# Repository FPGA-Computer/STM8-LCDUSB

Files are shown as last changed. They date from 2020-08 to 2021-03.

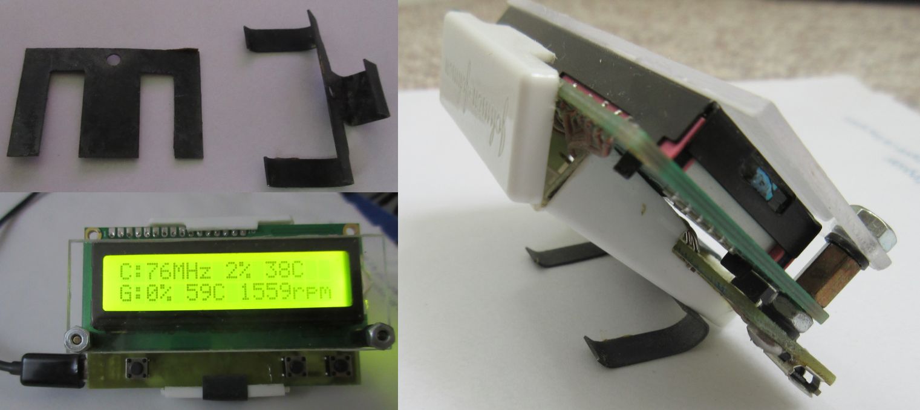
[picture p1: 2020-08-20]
LCD stand.jpg

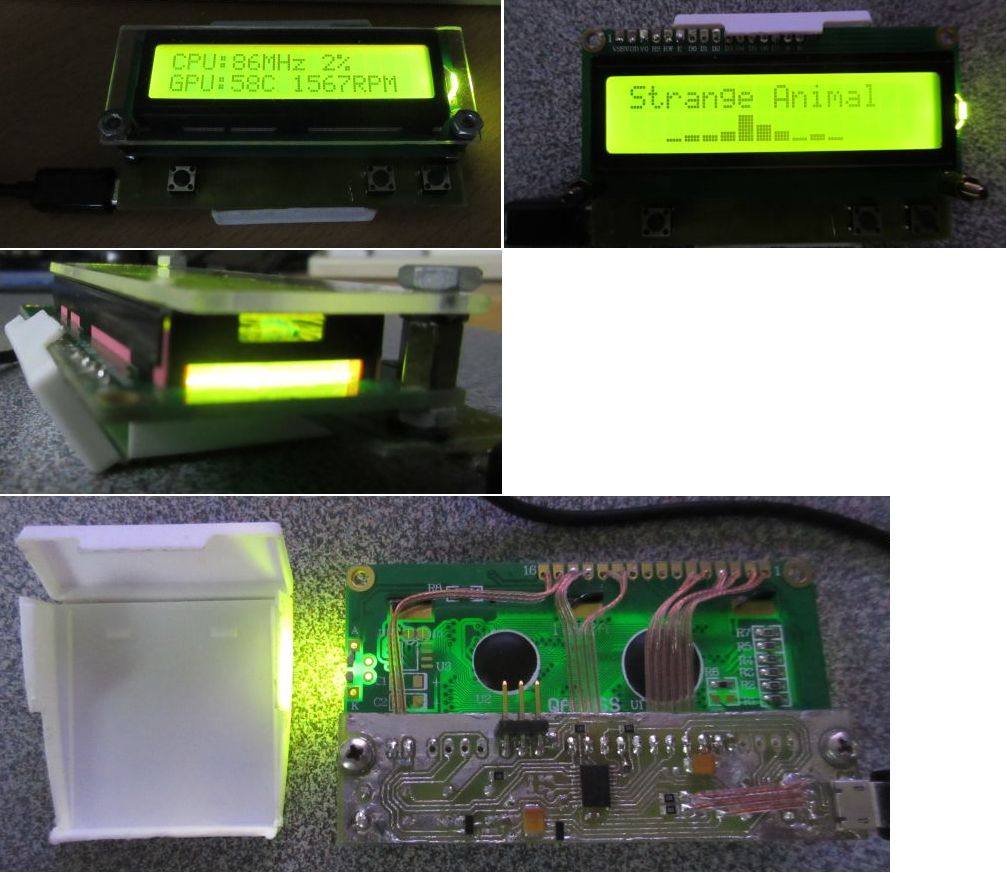
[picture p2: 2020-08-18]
LCD2USB.jpg

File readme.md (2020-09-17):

#STM8-LCD2USB

The firmware only USB stack is an unofficial fork from STM8S-VUSB-KEYBOARD at https://github.com/BBS215/STM8S-VUSB-KEYBOARD

- Russian comments "google translated" to English.  Minimal changes to the original are in .zip file.

- Works with current special edition of Cosmic C (4.4.10) and current version of STVD (4.3.12)

STM8 LCD2USB

- LCD2USB port from ATMega8 to STM8S003. It is working with LCD Smarties.  Only 1 LCD controller supported i.e. no support for larger display. If the LCD is accessed with delays (Not implemented) instead of polling, the GPIO for R/W can be repurposed as Enable pin (E).

LCD2USB at https://github.com/harbaum/LCD2USB  (LCD2USB.dll)

LCD Smarties at http://lcdsmartie.sourceforge.net/

- USB stack logic is modified for this tech demo. Vendor Request packets (needed by LCD2USB) is working.  HID now tested (STM8 HID Dial).

- Code reformatted/refractored.  Using my own IRQ files for STM8S003 for a much cleaner organization.  

- No longer need a separate GPIO for the 1.5K pull up to connect/disconnect USB.  See schematic.

- Device library calls have been changed to bare metal to minimized dependancy and reduce code size.  stm8s_flash.c is the only library needed.

- "Port C pins can only be used as GPIO inputs" is no longer the case. They can be configured as PWM and force them Low/High via CCMRx registers.  See hardware.h

- The PCB is a general purpose single sided PCB. Serial port, I2C are broken out to headers, pads for tiny crystal and load capacitors available for oscillator. 
The buttons are also used as jumpers for Gnd.  Install 2 jumpers under buttons S1 and S2 if they are not used.  LCD mounting holes and pinouts are for common 1602A from China.

Note: 

The USB stack calibrates the HSI clock while connected to the PC. The calibration is store in EEPROM. It can take a couple of minutes the first time before it functions correctly.

Timer 1 is used by the USB stack for filtering and interrupt. It is not actually used for counting.

R7 value control brightness.  I use R7 = 330R for my green display and 2.7K for my white ones.

Changes:

- New STM8_LCD2USB.dll for 3 buttons support. I took a bit of effort for me to learn to compile a .DLL, so I have included source + solution file for vs_Community (Visual Studio Community 2019
Version 16.7.2) with C++ (2019).  I am using libusb-win32-bin-1.2.7.1.zip to create this.

- Buttons: return by $MObutton

  * Long press 'OR' 0x10 to the individual keys values.

  * Multiple keys pressed at the same time have their values 'OR' together

Action|Menu (S1)| Inc (S2)|Dec (S3)
------|---------|---------|--------
Quick press|1|4|2
Long Press|A|D|B

V1.1

- VUSB library is updated for HID.  Logic changes and more refractoring.  It is used in my other project: STM8 HID Dial.

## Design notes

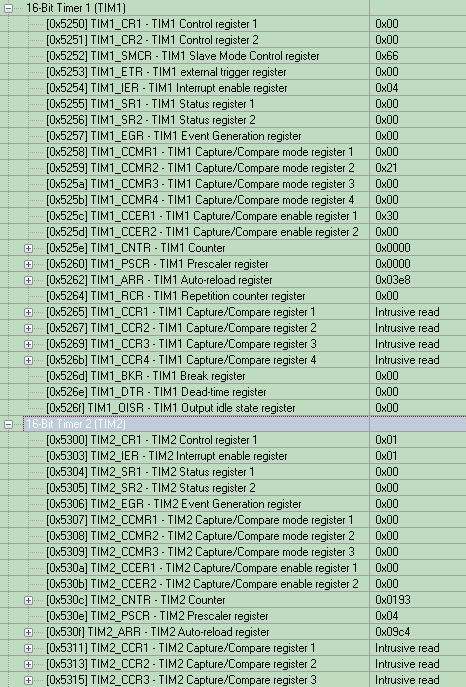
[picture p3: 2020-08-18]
LCD2USB/timers.png

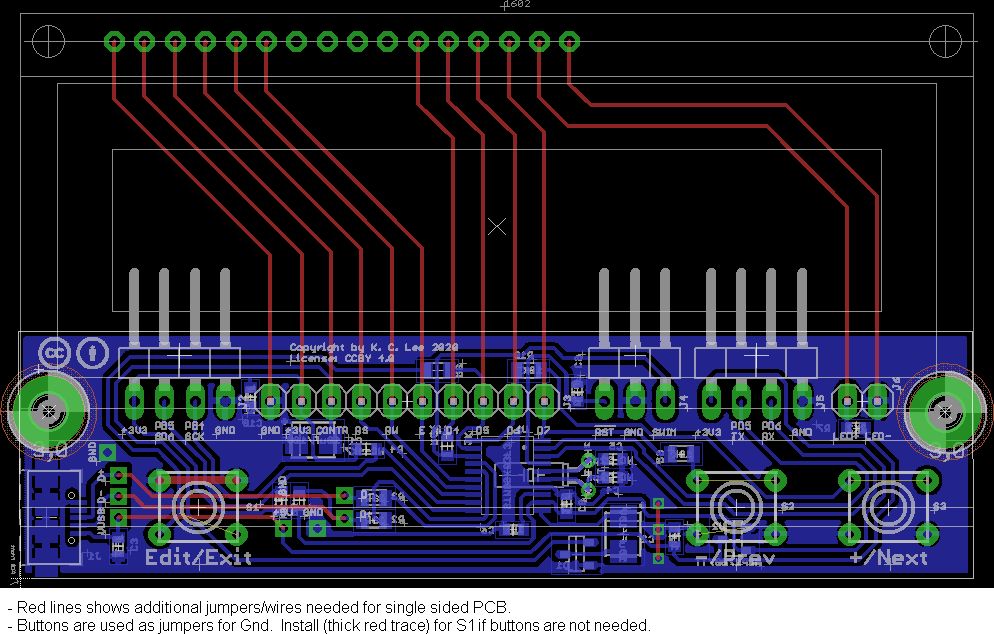
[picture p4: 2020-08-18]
Eagle Cad/PCB.jpg

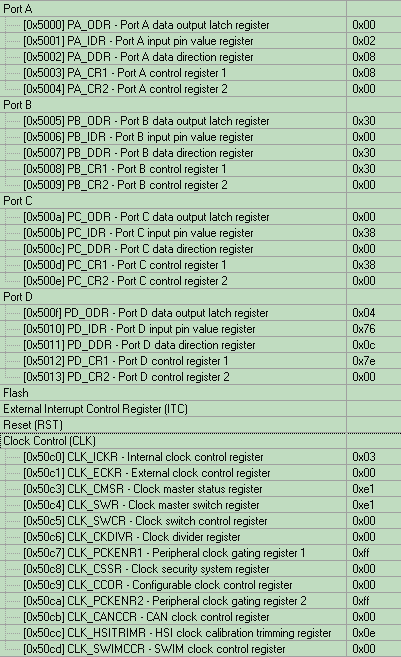
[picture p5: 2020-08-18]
LCD2USB/gpio clk.png

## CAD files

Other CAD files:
LCD2USB/stm8_vusb.stp
LCD2USB/stm8_vusb_Programmer/stm8_vusb_STVP.stp

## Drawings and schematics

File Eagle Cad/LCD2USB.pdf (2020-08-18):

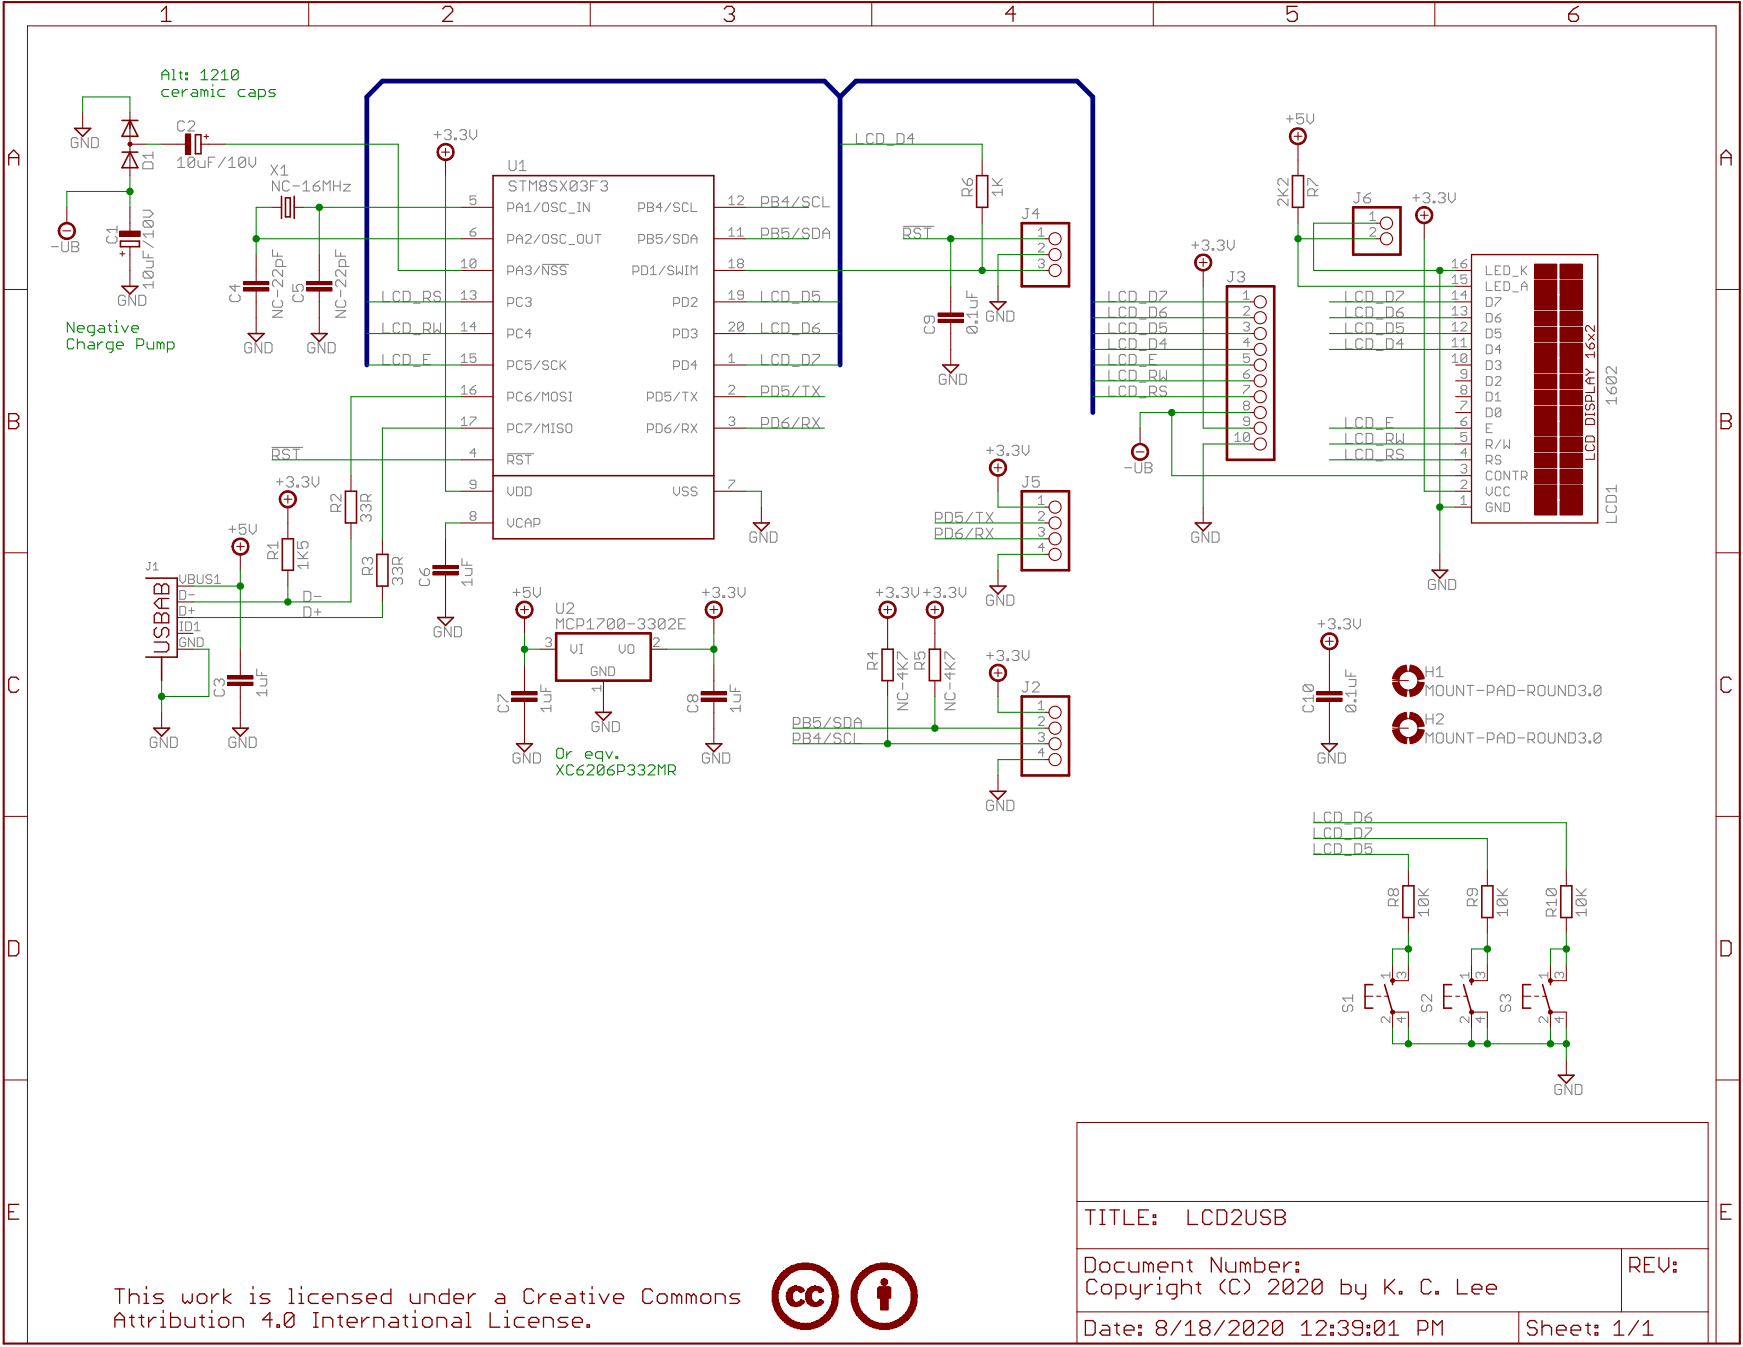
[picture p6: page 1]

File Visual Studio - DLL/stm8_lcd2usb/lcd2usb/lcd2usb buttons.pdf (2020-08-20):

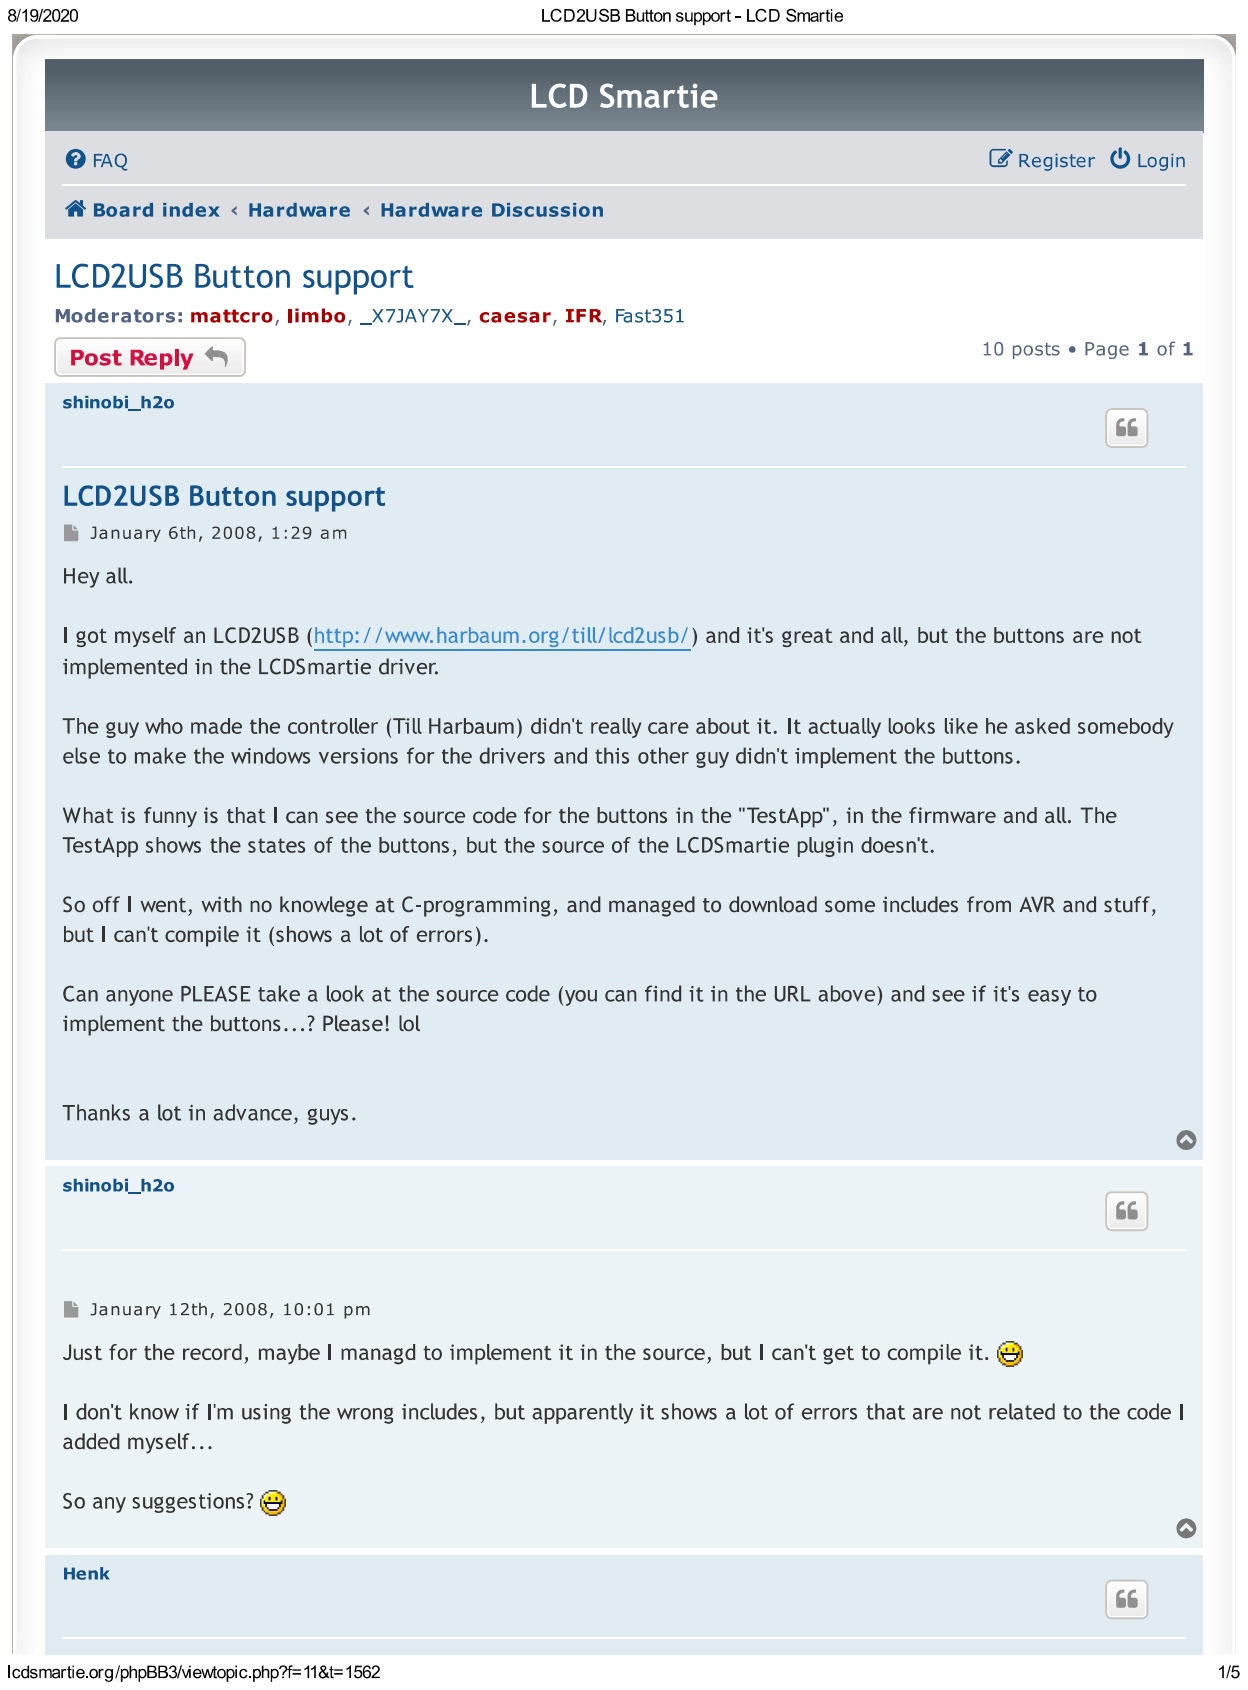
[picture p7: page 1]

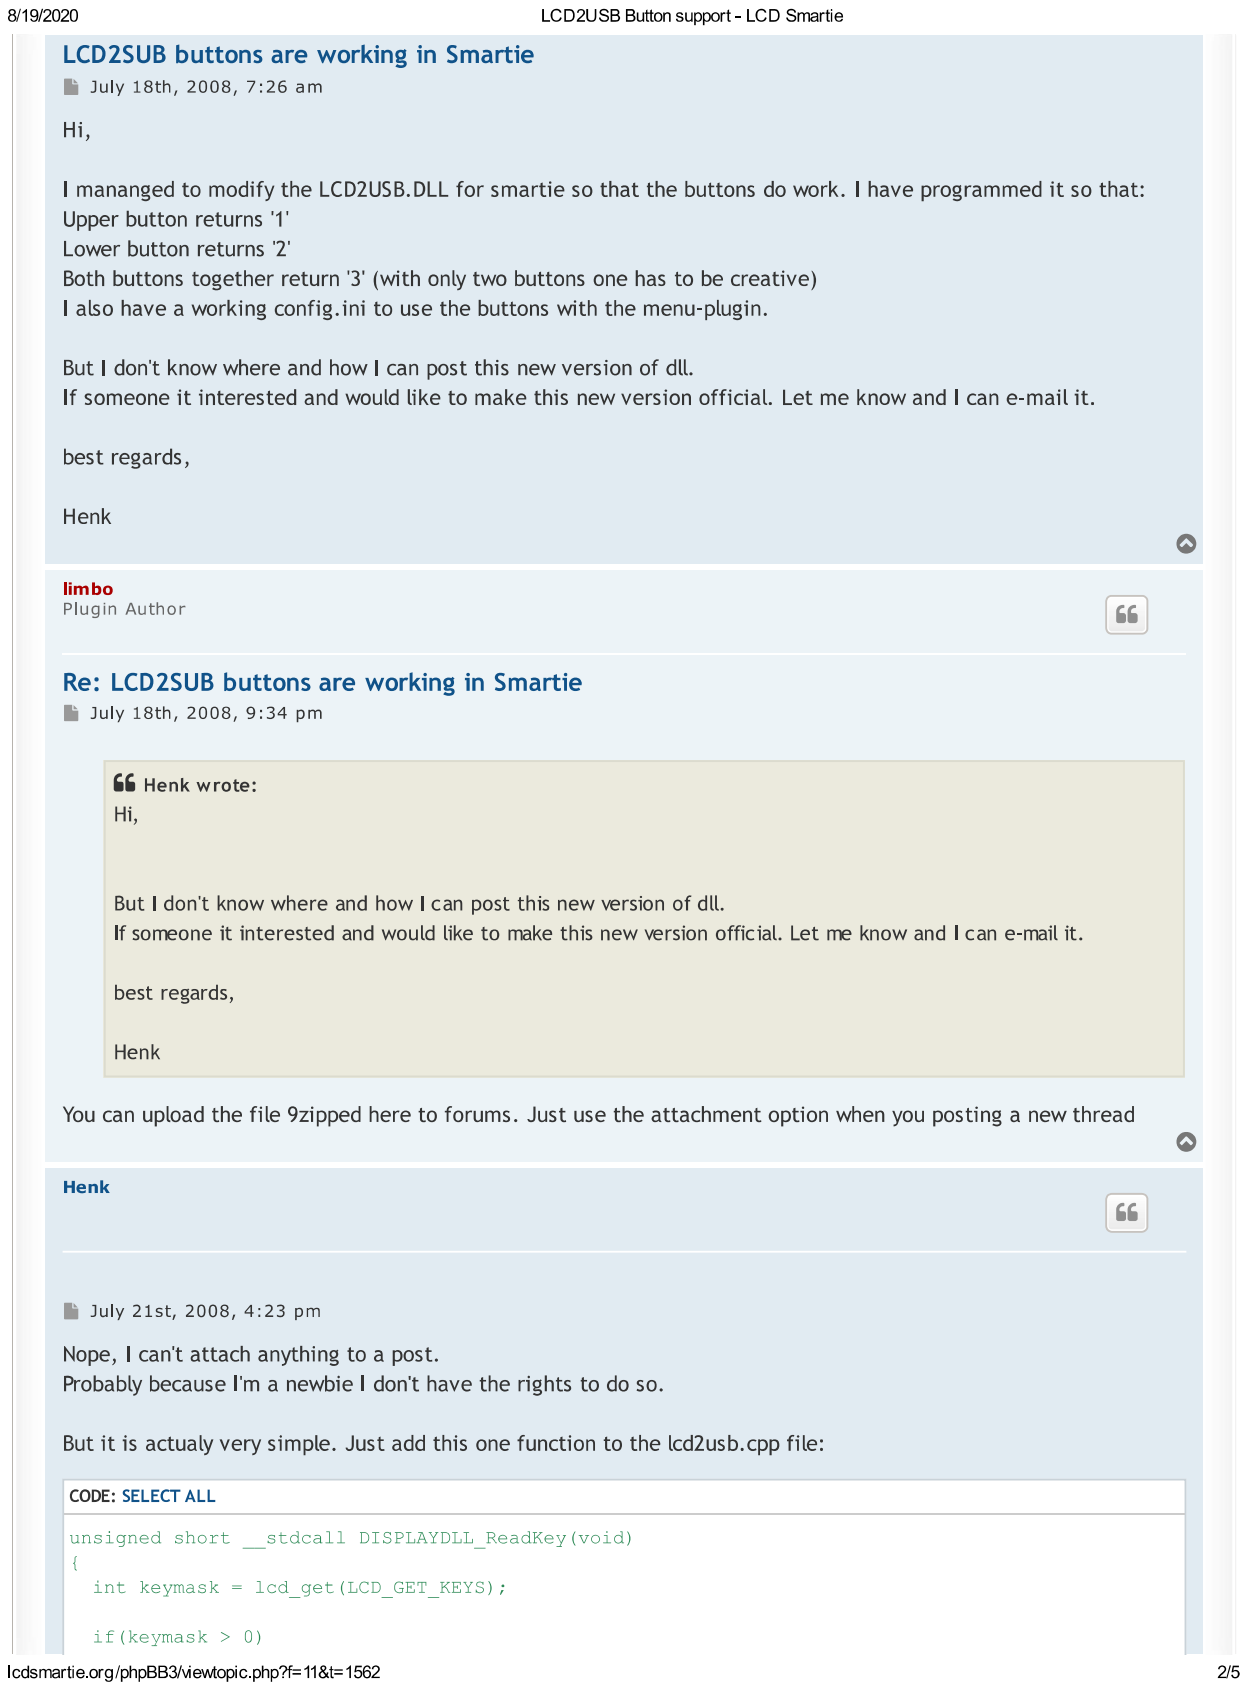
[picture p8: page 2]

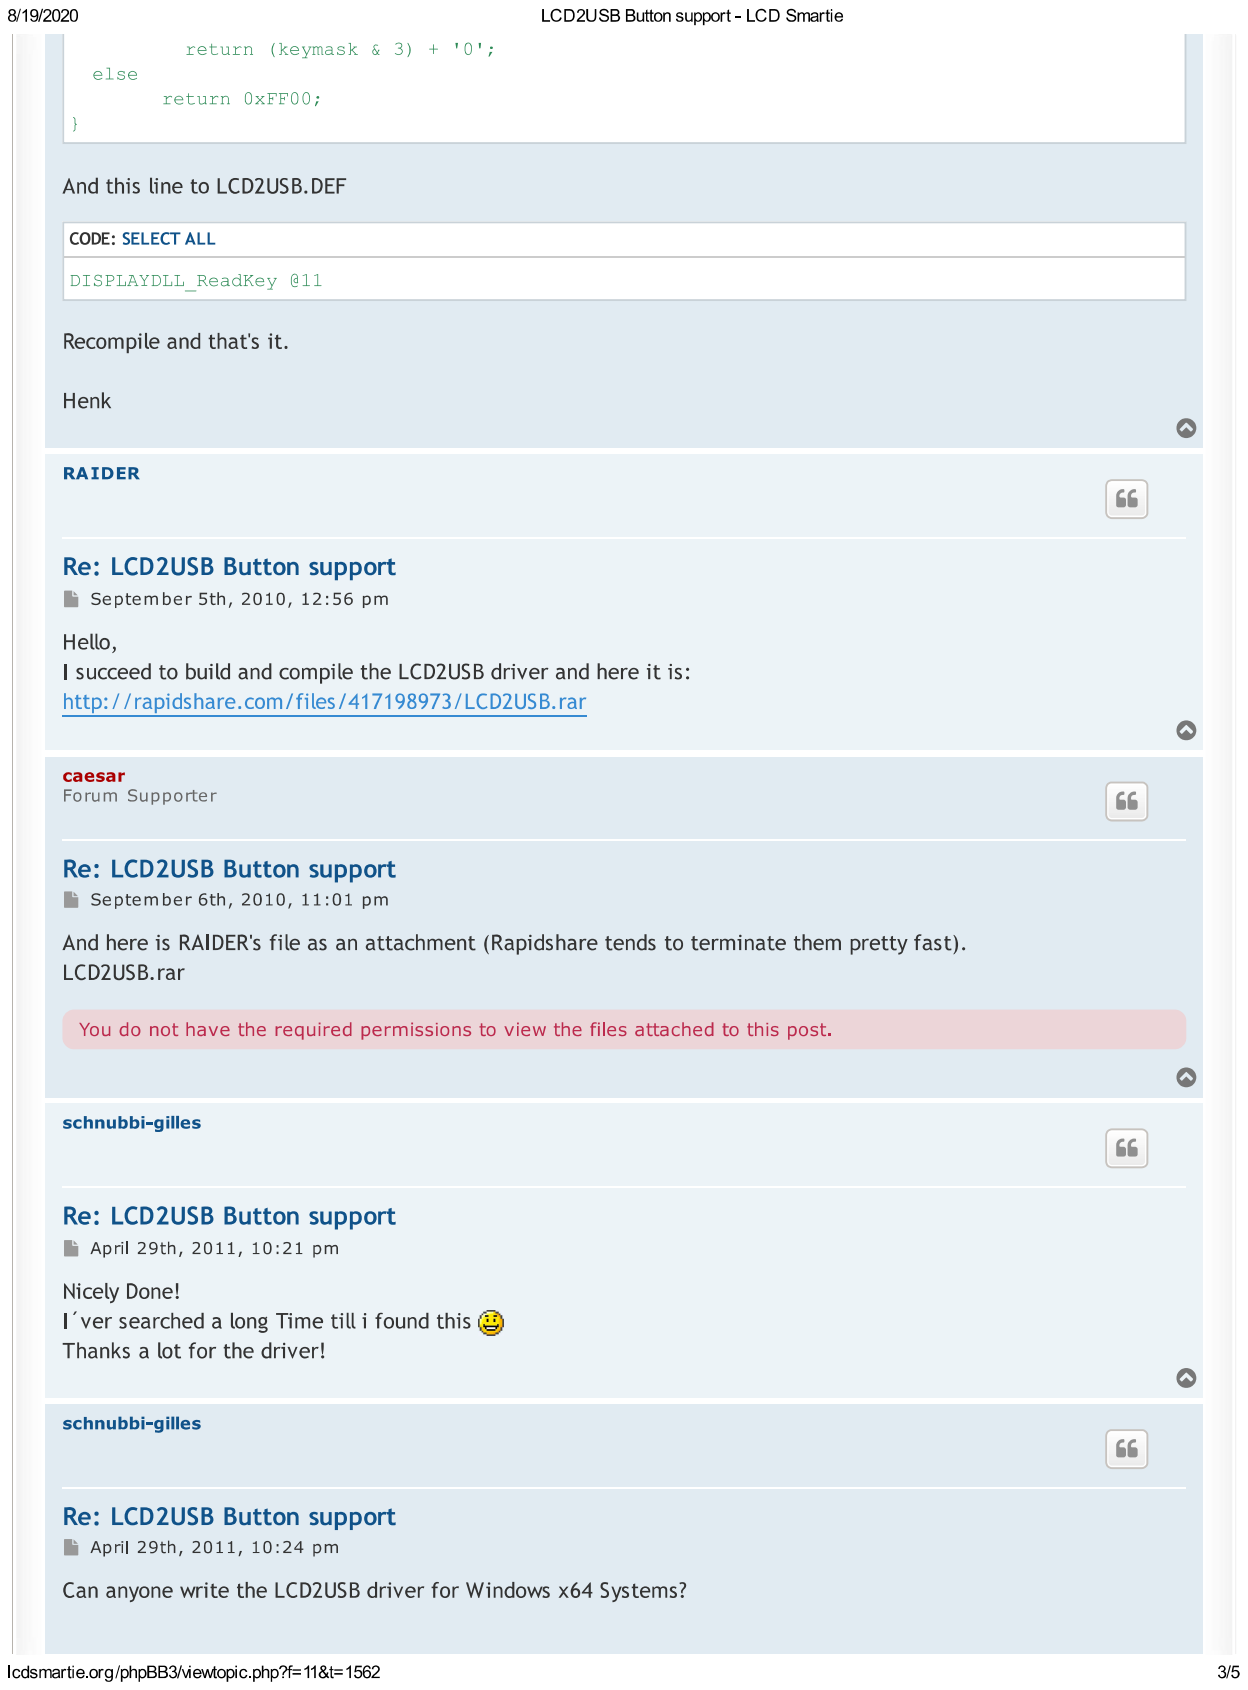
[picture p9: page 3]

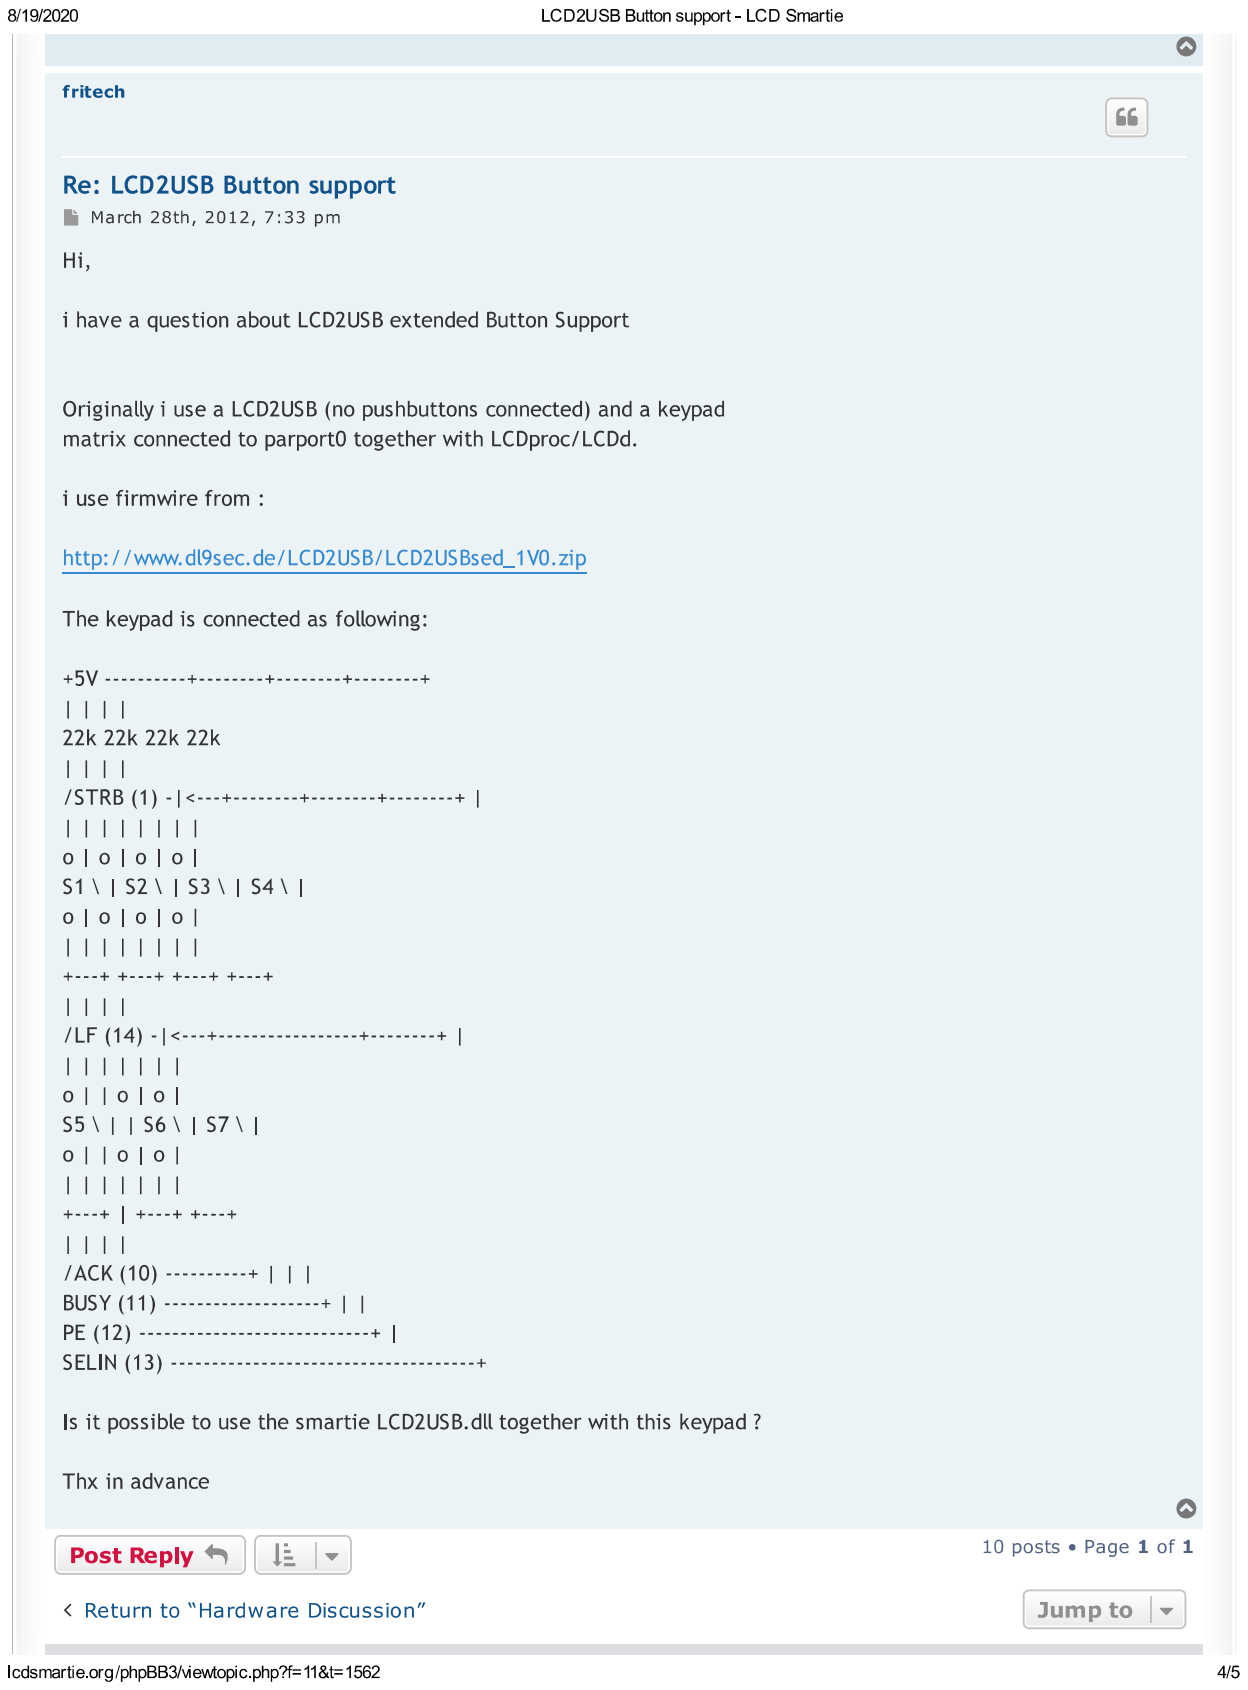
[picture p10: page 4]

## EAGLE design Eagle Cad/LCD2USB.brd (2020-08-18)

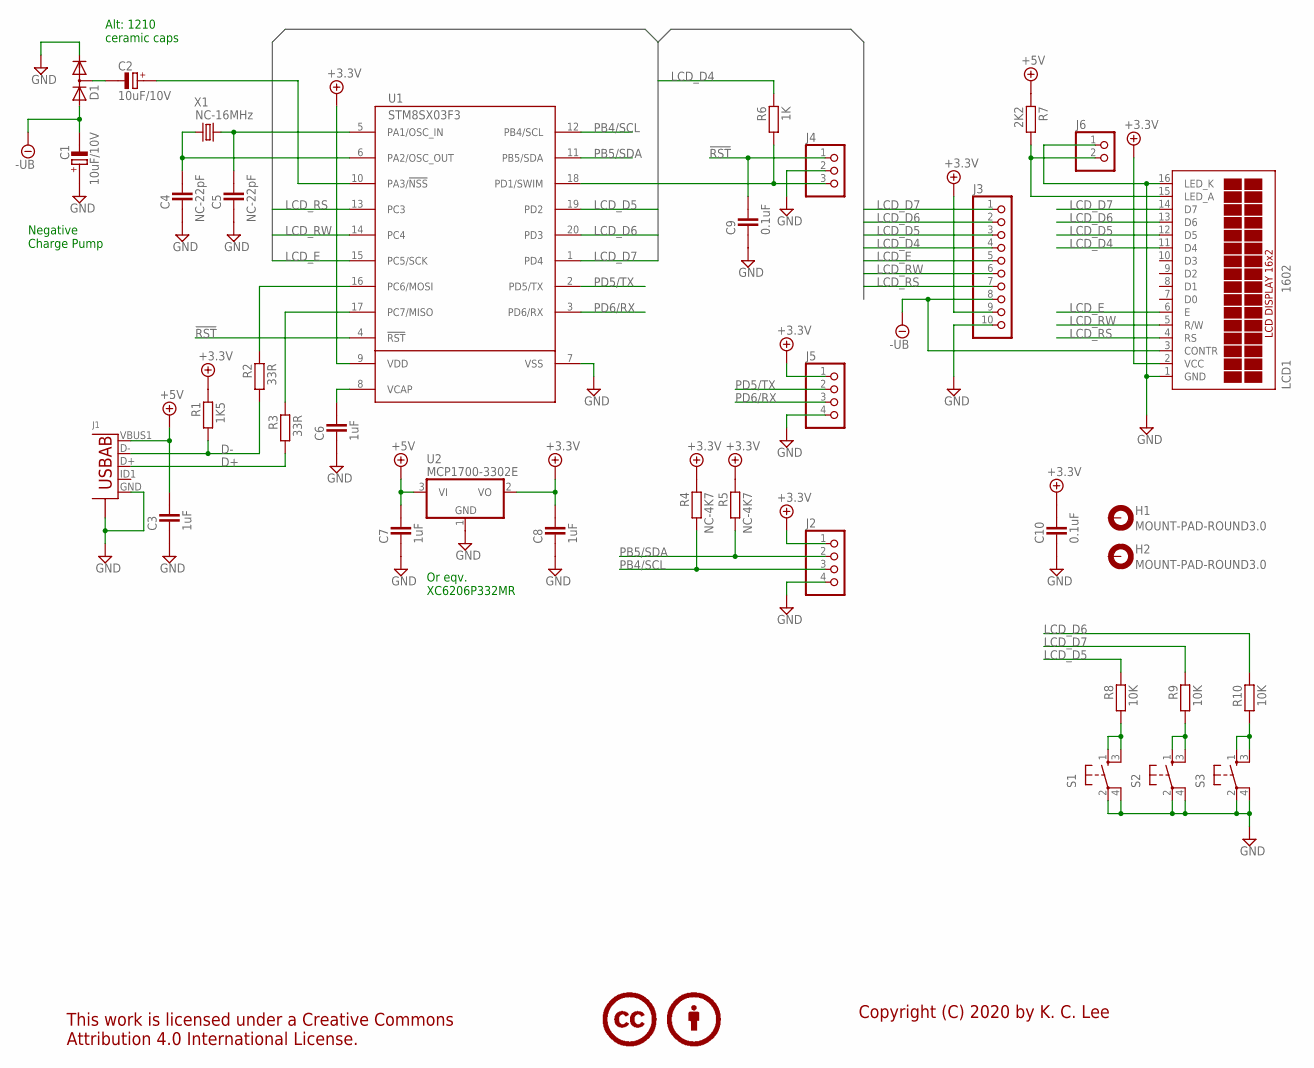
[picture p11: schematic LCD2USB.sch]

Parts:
C1, C2: 10uF/10V; CAPMP3528X210N
C3, C6, C7, C8: 1uF; CAPC1608X92N
C4, C5: NC-22pF; CAPC1608X92N
C9, C10: 0.1uF; CAPC1608X92N
D1: KA2KA_SOT-23; SOT95P280X135-3N
H1, H2: MOUNT-PAD-ROUND3.0; 3,0-PAD
J1: USB-ABBG-ORG; USB-AB-MICRO-SMD_V03_SMT
J2, J5: PINHD-1X4_2.54-90°; 1X04/90
J3: PINHD-1X10_2.54; 1X10
J4: PINHD-1X3_2.54-90°; 1X03/90
J6: PINHD-1X2_2.54; 1X02
LCD1: 1602; TUXGR_16X2_R2_NM
LICENSE1: CC-BY100%; CC-BY-100
R1: 1K5; RESC1608X55N
R2, R3: 33R; RESC2012X70N
R4, R5: NC-4K7; RESC1608X55N
R6: 1K; RESC1608X55N
R7: 2K2; RESC1608X55N
R8, R9, R10: 10K; RESC2012X70N
S1, S2, S3: MOM_SWTH; MOM_SW
U1: STM8SX03F3; TSSOP20
U2: MCP1700-3302E; SOT95P280X135-3N
X1: NC-16MHz; TC26H

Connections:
!RST: C9.2, J4.1, U1.4 (!RST)
+3.3V: C8.2, C10.2, J2.1, J3.9, J5.1, LCD1.2 (VCC), R1.1, R4.1, R5.1, U1.9 (VDD), U2.2 (VO)
+5V: C3.2, C7.2, J1.VBUS1 (VBUS), R7.1, U2.3 (VI)
-UB: C1.-, D1.1 (A), J3.8, LCD1.3 (CONTR)
D+: J1.D+, R3.2
D-: J1.D-, R1.2, R2.2
GND: C1.+, C3.1, C4.1, C5.1, C6.1, C7.1, C8.1, C9.1, C10.1, D1.2 (K), J1.GND, J1.S1 (S), J1.S2 (S), J1.S3 (S), J1.S4 (S), J2.4, J3.10, J4.2, J5.4, J6.1, LCD1.1 (GND), LCD1.16 (LED_K), S1.2 (3), S1.4, S2.2 (3), S2.4, S3.2 (3), S3.4, U1.7 (VSS), U2.1 (GND)
LCD_A: J6.2, LCD1.15 (LED_A), R7.2
LCD_D4: J3.4, LCD1.11 (D4), R6.1
LCD_D5: J3.3, LCD1.12 (D5), R8.1, U1.19 (PD2)
LCD_D6: J3.2, LCD1.13 (D6), R10.1, U1.20 (PD3)
LCD_D7: J3.1, LCD1.14 (D7), R9.1, U1.1 (PD4)
LCD_E: J3.5, LCD1.6 (E), U1.15 (PC5/SCK)
LCD_RS: J3.7, LCD1.4 (RS), U1.13 (PC3)
LCD_RW: J3.6, LCD1.5 (R/W), U1.14 (PC4)
unnamed: C6.2, U1.8 (VCAP)
unnamed: R3.1, U1.17 (PC7/MISO)
unnamed: C5.2, U1.5 (PA1/OSC_IN), X1.1
unnamed: C4.2, U1.6 (PA2/OSC_OUT), X1.2
unnamed: R2.1, U1.16 (PC6/MOSI)
unnamed: R8.2, S1.1, S1.3 (2)
unnamed: C2.+, U1.10 (PA3/!NSS)
unnamed: C2.-, D1.3 (KA)
unnamed: J4.3, R6.2, U1.18 (PD1/SWIM)
unnamed: R9.2, S2.1, S2.3 (2)
unnamed: R10.2, S3.1, S3.3 (2)
PB4/SCL: J2.3, R4.2, U1.12 (PB4/SCL)
PB5/SDA: J2.2, R5.2, U1.11 (PB5/SDA)
PD5/TX: J5.2, U1.2 (PD5/TX)
PD6/RX: J5.3, U1.3 (PD6/RX)

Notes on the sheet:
Copyright (C) 2020 by K. C. Lee
Negative Charge Pump
Alt: 1210 ceramic caps
Or eqv. XC6206P332MR

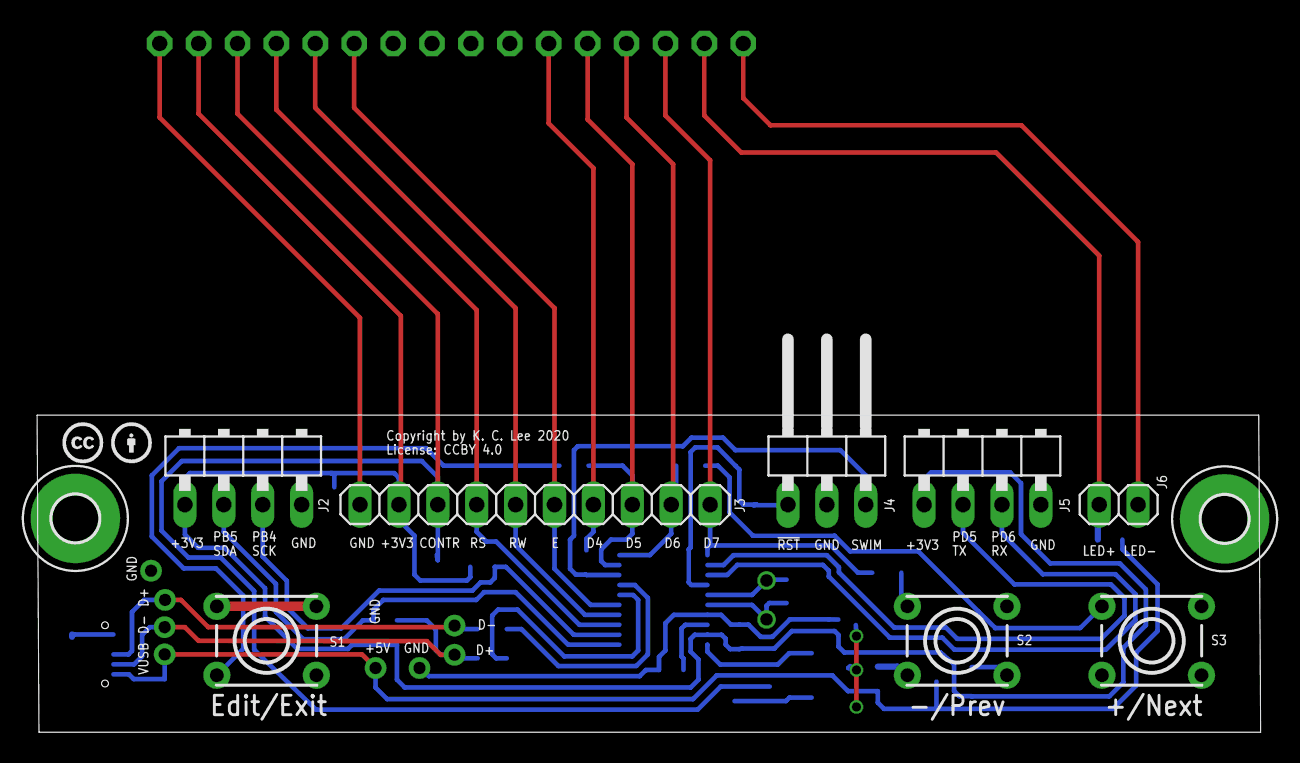
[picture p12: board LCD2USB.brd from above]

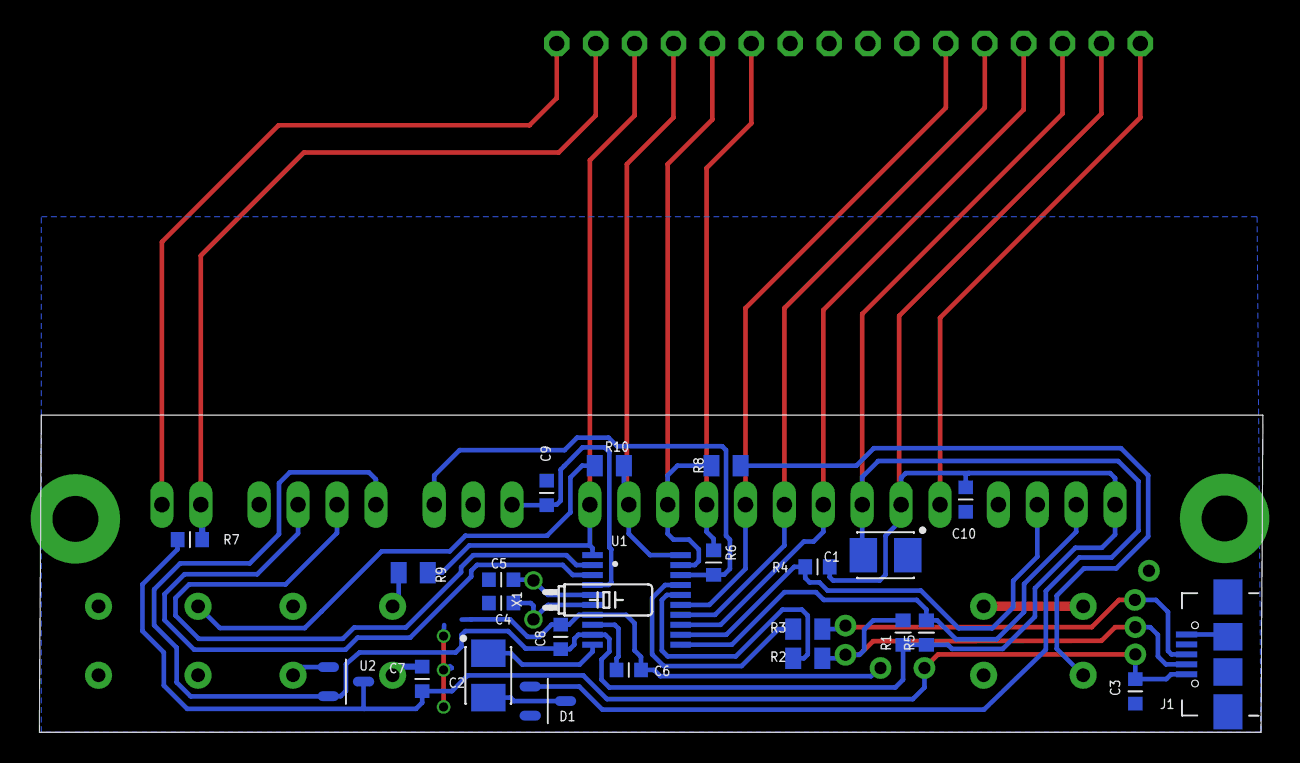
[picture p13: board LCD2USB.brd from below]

Board: 2 copper layers, 79.9 x 20.7 mm, 37 parts (25 on the bottom side), 30 nets.

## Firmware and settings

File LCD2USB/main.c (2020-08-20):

#include "main.h"
#include "usb.h"
#include "hardware.h"
#include "LCD.h"

/*
	USB_EP0_RxReady_callback is pre-assigned for data processing,
	EP0 in the Data stage process.
*/

void USB_EP0_RxReady_callback(uint8_t *p_data, uint8_t length)
{
	if (length == 0) 
		return;

}

/*
USB_Class_Init_callback is called upon initiation
USB powered device.
*/
int8_t USB_Class_Init_callback(uint8_t dev_config)
{
	return 0;
}

/*
	USB_Class_DeInit_callback is called upon reset.
	USB powered device.
*/
int8_t USB_Class_DeInit_callback(void)
{
	return 0;
}

/*
	USB_Setup_Request_callback is called for processing USB requests,
	Not included in the standard USB stack.
*/
#define VERSION_MAJOR 1
#define VERSION_MINOR 9
#define VERSION_STR "1.09"

uint8_t replyBuf[2];

int8_t USB_Setup_Request_callback(t_USB_SetupReq *p_req)
{
	uint8_t len = (uint8_t)((p_req->bRequest & 0x03)+1);  // 1 .. 4 bytes
	uint8_t target = (uint8_t)((p_req->bRequest>>3)&0x03);
	uint8_t *data = (uint8_t *)p_req;
	uint8_t i,ReplySize = 0;
	
	if((p_req->bmRequest & USB_REQ_TYPE_MASK)!=USB_REQ_TYPE_VENDOR)
		return -1;
		
	// request byte:
	// 7 6 5 4 3 2 1 0
	// C C C T T R L L			

	switch(p_req->bRequest>>5)														// Command
	{
		case 0: // echo (for transfer reliability testing)
			replyBuf[0] = data[2];
			replyBuf[1] = data[3];
			ReplySize = 2;
			break;
			
		case 1: // LCD command
			if(target==1)
				for(i=0;i<len;i++)
					LCD_Cmd(data[2+i]);
			break;
	
		case 2: // LCD data
			if(target==1)
				for(i=0;i<len;i++)
					LCD_Data(data[2+i]);
			break;
	
		case 3: // set
		
			if(target==0)	// contrast
				LCD_Contrast(data[2]);
			break;
	
		case 4: // get
			ReplySize = 2;
			
			switch(target)
			{	
				case 0: // version
					replyBuf[0] = VERSION_MAJOR;
					replyBuf[1] = VERSION_MINOR;
					break;
		
				case 1: // keys
					replyBuf[0] = Key_Get();
					//replyBuf[0] = (uint8_t)((~(LCD_DATA_PORT->IDR)>>KEY_DOFFSET)&KEY_MASK);
					replyBuf[1] = 0;
					break;
		
				case 2: // controller map
					replyBuf[0] = 1;
					replyBuf[1] = 0;
					break;      
		
				default:
					// must not happen ...
					ReplySize = 0;
					break;      
			}
	}
	
	USB_Send_Data(replyBuf,ReplySize,0);
	return 0;
}

/*
	USB_EP1_RxReady_callback is pre-assigned for data processing,
  Pins EP1. In this example, it is not used.
*/
void USB_EP1_RxReady_callback(uint8_t *p_data, uint8_t length)
{
	// Nothing. Really.
}

/// MAIN ///////////////////////////////////////////////////

void main(void)
{
	uint8_t counter = TIM2_CNTMAX;
	
	Init_Hardware();

	while(1)
	{
		USB_loop(); // A "quick" USB loop for processing requests
		
		if (TIM2_Update_Flag)	// 400 Hz call
		{ 
			TIM2_Update_Flag = 0;
			
			if (!counter)
			{
				counter--;
			}
			else
			{ // 100 Hz call
				counter = TIM2_CNTMAX;
				USB_slow_loop(); // "slow" USB loop for setting HSI generator and EP1 watchdog
				KeyScan();
			}
		}
	}
}

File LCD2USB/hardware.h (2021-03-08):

/*
 * hardware.h
 *
 * Created: October 31, 2019, 12:33:01 PM
 *  Author: K. C. Lee
 * Copyright (c) 2019 by K. C. Lee
 
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
 If not, see http://www.gnu.org/licenses/gpl-3.0.en.html 
 */ 

#ifndef HARDWARE_H_
#define HARDWARE_H_

#ifndef __CSMC__
#define __CSMC__
#endif
#ifndef STM8S003
#define STM8S003
#endif

#include "stm8s.h"
#include <stdio.h>

// STM8S003F3P6
enum _PA { PA1=0x02, PA2=0x04, PA3=0x08 };
enum _PB { PB4=0x10, PB5=0x20 };
enum _PC { PC3=0x08, PC4=0x10, PC5=0x20, PC6=0x40, PC7=0x80 };
enum _PD { PD1=0x02, PD2=0x04, PD3=0x08, PD4=0x10, PD5=0x20, PD6=0x40 };

#define GPIO(X)					((GPIO_TypeDef *)(X))

#define CPU_CLOCK				16000000UL
#define EE_Addr					0x4000

#define LCD_BIAS_PORT		GPIOA
#define LCD_BIAS_PIN		PA3

enum _OPT2 { AFR0 = 0x01, AFR1=0x02, AFR2=0x04, AFR3=0x08, AFR4=0x10, AFR5=0x20, AFR6=0x40, AFR7 = 0x80 };
enum _OPT3 { HSITRIM = 0x10, LSI_EN = 0x08, IWDG_HW = 0x04, WWDG_HW = 0x02, WWDG_HALT = 0x01 };

#define TIM2_PRSC				4
#define TIM2_FREQ				400
#define TIM2_Slow				100
#define TIM2_CNTMAX			(TIM2_FREQ/TIM2_Slow)
#define TIM2_RELOAD			(CPU_CLOCK/(1<<TIM2_PRSC)/TIM2_FREQ)

// fake output for PC[5..3]

// Control PC5
#define Clr_PC5()				TIM2->CCMR1 = (0x4<<4)
#define Set_PC5()				TIM2->CCMR1 = (0x5<<4)
#define Clr_PC4()				TIM1->CCMR4 = (0x4<<4)
#define Set_PC4()				TIM1->CCMR4 = (0x5<<4)
#define Clr_PC3()				TIM1->CCMR3 = (0x4<<4)
#define Set_PC3()				TIM1->CCMR3 = (0x5<<4)

// LCD GPIO mapping
#define Clr_LCD_E()			Clr_PC5()
#define Set_LCD_E()			Set_PC5()
#define Clr_LCD_RW()		Clr_PC4()
#define Set_LCD_RW()		Set_PC4()
#define Clr_LCD_RS()		Clr_PC3()
#define Set_LCD_RS()		Set_PC3()

#define LCD_DATA_PORT		GPIOD
#define LCD_DATA				(PD4|PD3|PD2|PD1)
#define LCD_DOFFSET			1
#define KEY_DOFFSET			(LCD_DOFFSET+1)

extern volatile uint8_t TIM2_Update_Flag;

void Init_Hardware(void);
void RESET_CHIP(void);
void Check_OPTION_BYTE(void);
void FLASH_Data_lock(uint8_t lock);
void FLASH_Wait(void);
void TIM2_Init(void);

void LCD_Init(void);
void Delay(uint16_t t);
uint8_t Key_Get(void);

// Delays in us.  The delay has been calibrated for 16MHz
// Maximum delay is about 100ms (16-bit)

#define DELAY_TWEAK			0.63
#define US_DELAY(X)			((uint16_t)(X*DELAY_TWEAK))

typedef struct
{
	uint8_t code;
	uint8_t count;
} key_t;

extern key_t key;

void KeyScan(void);

#define KEY_REPEAT_RATE		4
#define KEY_THRESHOLD			3
#define KEY_REPEAT_WAIT		0.75

#define KEY_CNT_MAX				(KEY_REPEAT_WAIT*TIM2_Slow+KEY_THRESHOLD)
#define KEY_RELOAD				(KEY_CNT_MAX-TIM2_Slow/KEY_REPEAT_RATE)

enum keys { KEY_MENU=0x01, KEY_DEC=0x02, KEY_INC=0x04, KEY_MASK= KEY_MENU|KEY_DEC|KEY_INC, 
						KEY_LONG=0x10, KEY_REPORTED=0x40, KEY_FLAG=0x80 };
						
#endif

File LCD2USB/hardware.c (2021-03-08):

/*
 * hardware.c
 *
 * Created: August 30, 2019, 6:35:08 PM
 *  Author: K. C. Lee
 * Copyright (c) 2016 by K. C. Lee
 
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
 If not, see http://www.gnu.org/licenses/gpl-3.0.en.html 
 */ 

#include "hardware.h"
#include "usb.h"
#include "lcd.h"

volatile uint8_t TIM2_Update_Flag;
key_t key;

void Init_Hardware(void)
{	
	Check_OPTION_BYTE();
	CLK->CKDIVR = 0; // HSIDIV = 0; CPUDIV = 0
	USB_disconnect();
	TIM2_Init();
	USB_Init();
	Delay(US_DELAY(90000));
	LCD_Init();
	enableInterrupts();
	USB_connect();
}

#define IWDG_KEY_ENABLE 0xcc

void RESET_CHIP(void)
{
	IWDG->KR = IWDG_KEY_ENABLE; // Reset the CPU: Enable the watchdog and wait until it expires
	while(1);    // Wait until reset occurs from IWDG
}

void FLASH_Data_lock(uint8_t lock)
{
	if(lock)
		FLASH->IAPSR = 0;
	else
	{
		/* Warning: keys are reversed on data memory !!! */
    FLASH->DUKR = FLASH_RASS_KEY2;
    FLASH->DUKR = FLASH_RASS_KEY1;		
	}
}

void FLASH_Wait(void)
{
	while(!(uint8_t)(FLASH->IAPSR & (FLASH_IAPSR_EOP | FLASH_IAPSR_WR_PG_DIS)))
		/* wait*/;
}

void Check_OPTION_BYTE(void)
{
	uint8_t option_byte;

	if ((OPT->OPT2 != (uint8_t)(~OPT->NOPT2))||((OPT->OPT2 & AFR0) == 0)) 
	{ // check AFR0
		option_byte = OPT->OPT2|AFR0; 		// set AFR0 = 1 // PORT C[7..5] Alternate Function
		
		FLASH_Data_lock(0);
		FLASH->CR2 |= FLASH_CR2_OPT;
		FLASH->NCR2 &= (uint8_t)(~FLASH_NCR2_NOPT);

		OPT->OPT2 = option_byte;
		FLASH_Wait();

		OPT->NOPT2 = (uint8_t)(~option_byte);
		FLASH_Wait();
		
		// Disable write access to option bytes
		FLASH->CR2 &= (uint8_t)(~FLASH_CR2_OPT);
		FLASH->NCR2 |= FLASH_NCR2_NOPT;

		FLASH_Data_lock(1);
    RESET_CHIP();
	}
	
	if ((OPT->OPT3 != (uint8_t)(~OPT->NOPT3))||((OPT->OPT3 & HSITRIM) == 0)) 
	{ // check HSITRIM
		option_byte = OPT->OPT3|HSITRIM;			// 4 bit on-the-fly trimming
		
		FLASH_Data_lock(0);
		FLASH->CR2 |= FLASH_CR2_OPT;
		FLASH->NCR2 &= (uint8_t)(~FLASH_NCR2_NOPT);

		OPT->OPT3 = option_byte;
		FLASH_Wait();

		OPT->NOPT3 = (uint8_t)(~option_byte);
		FLASH_Wait();
		
		// Disable write access to option bytes
		FLASH->CR2 &= (uint8_t)(~FLASH_CR2_OPT);
		FLASH->NCR2 |= FLASH_NCR2_NOPT;
		FLASH_Data_lock(1);
    RESET_CHIP();
	}
}

void TIM2_Init(void)
{
	// TIM2_TimeBaseInit(TIM2_PRESCALER_16, 2500); // 16 MHz / 16 / 2500 = 400 Hz	
	TIM2->PSCR = TIM2_PRSC;
	TIM2->ARRH = TIM2_RELOAD >>8;
	TIM2->ARRL = TIM2_RELOAD & 0xff;
	
	//	TIM2_ITConfig(TIM2_IT_UPDATE, ENABLE);
	TIM2->IER = TIM2_IER_UIE;

	// TIM2 enable
	TIM2->CR1 = TIM2_CR1_CEN;
}

// 400Hz IRQ handler
@far @interrupt void TIM2_Update_IRQ(void)
 {
	TIM2_Update_Flag = 1;
	TIM2->SR1 = (uint8_t)~TIM2_SR1_UIF;
 }

void LCD_Init(void)
{
	// PWM - LCD contrast control - charge pump
	// CH3: PWM mode 1, preload enable
	TIM2->CCMR3 = (0x06<<4)|TIM2_CCMR_OCxPE;
	TIM2->CCER2 |= TIM2_CCER2_CC3E;				// CH3 output enable
	
	// PC5: TIM2_CH1: fake output port by using PWM mode
	TIM2->CCER1 |= TIM2_CCER1_CC1E;				// CH1 output enable
	
	// PC3: TIM1_CH4: fake output port by using PWM mode
	// PC2: TIM1_CH3: fake output port by using PWM mode
	TIM1->BKR |= TIM1_BKR_MOE;						// Main output enable
	TIM1->CCER2 |= TIM1_CCER2_CC3E|TIM1_CCER2_CC4E;	// CH3, CH4 output enable
	
	LCD_DATA_PORT->CR1 |= LCD_DATA;				// Set push-pull/pull up
	
	LCD_Contrast(LCD_DEFAULT_CONTRAST);
	LCD_SetMode();
}

// Delay in us
void Delay(uint16_t t)
{
	for(;t;t--)
		LCD_Short_Delay();
}

void KeyScan(void)
{
	uint8_t new_code = (uint8_t)((~(LCD_DATA_PORT->IDR)>>KEY_DOFFSET)&KEY_MASK);

	if(new_code==(key.code & KEY_MASK))
	{
		if(new_code)
		{
			if(key.count == KEY_CNT_MAX)
			{	
				if(!(new_code&KEY_MENU))						// no auto-repeat for menu key
					key.count = (uint8_t)KEY_RELOAD;
				
				key.code |= KEY_LONG|KEY_FLAG;
			}
			else
				key.count++;
		}
	}
	else
	{
		if(!new_code&&key.code&&(key.count>KEY_THRESHOLD)&&!(key.code&(KEY_REPORTED|KEY_LONG)))
			key.code|=KEY_FLAG;
		else
		{
			key.code = new_code;
			key.count = 0;
		}
	}
}

uint8_t Key_Get(void)
{ 
  if(key.code & KEY_FLAG)
	{
		key.code = (uint8_t)((key.code & ~KEY_FLAG)|KEY_REPORTED);
		return(uint8_t)(key.code & (KEY_MASK|KEY_LONG));
	}
	return(0);
}

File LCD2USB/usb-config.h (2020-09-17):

#ifndef USB_CONFIG_H_
#define USB_CONFIG_H_

/// SETTINGS ///////////////////////////////////////////////
#define USB_MAX_NUM_CONFIGURATION 	1 // device configuration
#define USB_MAX_NUM_INTERFACES 			1 // device interfaces
#define USB_SELF_POWERED						0 // 0 - power from USB, 1 - dedicated power supply
#define USB_CLOCK_HSI								1	// 0 - external frequency to 16 MHz (PA1, PA2); 1 - from the internal RC generator (HSI)
#define USB_CONNECT_TIMEOUT					700 // connection timeout before reset // 100Hz * 7 sec = 700
#define USB_RECONNECT_DELAY					100 // 100Hz * 1 sec = 100

#define USB_RESET_DELAY							2000		// time to detect "USB RESET" // 5-7ms
//#define USB_EP_WATCHDOG_ENABLE			1 		// when EP is unavailable
#define USB_EP_WATCHDOG_TIMEOUT			300 		// timeout 3 sec
#define USB_EP_WATCHDOG_RECONNECT_DELAY	100 // Delay between switching off and on // 100Hz * 1 sec = 100

#define EEPROM_START_ADDR						0x4000 	// EEPROM location where the HSI flask and HSITRIM value are written (2 bytes)

#define MAGIC_VAL										0x11 		// HSI setup flag. If the EEPROM contains a different value, the HSI setting will start at zero.

// Optional features
//#define USB_CFG_HID_DESCRIPTORS						// handle USB HID descriptors
//#define USB_CFG_FEATURES_SUPPORT					// Support Set/Clear feature


#endif

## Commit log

2020-08-18 Initial release
    [LCD2USB.brd, LCD2USB.sch, stm8_vusb.stp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]
2020-08-20 Add LCD GPIO init
    [stm8_vusb.stp]
2020-08-20 Add button support - STM8_LCD2USB.dll
2020-08-20 tweak buttons parms
2020-08-20 fixing readme.md vs README.md - finger crossed
2020-09-17 VUSB library update - added HID support
    [stm8_vusb.stp]
2021-03-08 Removed library - smaller code
    [stm8_vusb.stp]

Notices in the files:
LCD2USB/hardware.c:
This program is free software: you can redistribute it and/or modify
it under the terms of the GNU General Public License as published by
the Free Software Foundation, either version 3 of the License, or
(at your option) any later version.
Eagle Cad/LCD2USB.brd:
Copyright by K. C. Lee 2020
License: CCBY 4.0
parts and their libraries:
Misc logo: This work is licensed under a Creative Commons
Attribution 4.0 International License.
